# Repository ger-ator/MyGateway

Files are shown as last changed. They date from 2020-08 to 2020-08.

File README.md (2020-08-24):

# MyGateway
RFM69 + ATSHA204A Shield for Arduino.

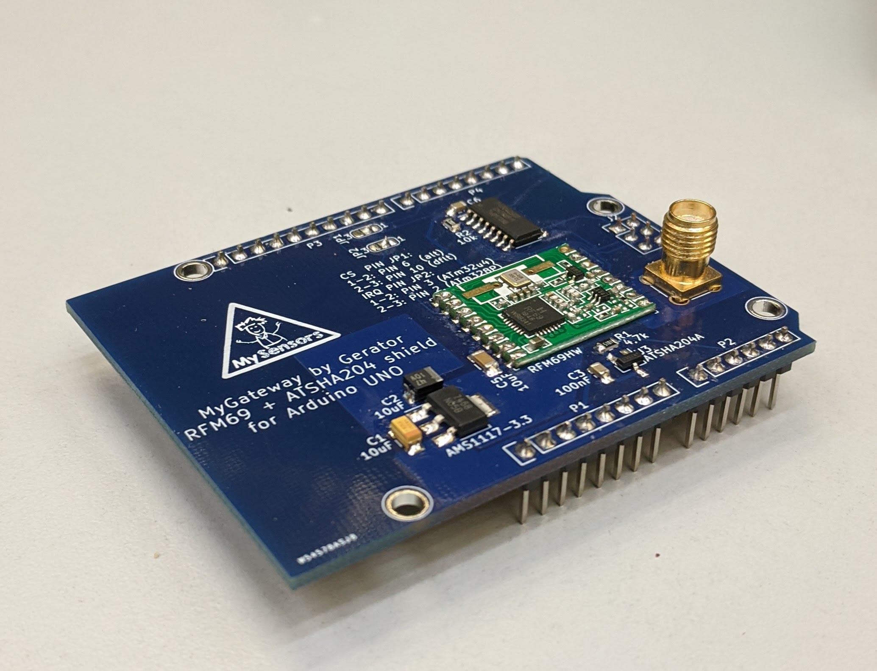
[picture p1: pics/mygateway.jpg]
MyGateway shield


# Description
This is another shield to build a MySensors gateway with Arduino UNO form factor. 
It includes RFM69 radio module and ATSHA204A crypto signing chip.

# Configuration
There are two jumpers to configure CS and IRQ RFM69 pins.
JP1 is used to choose between pins 6 or 10 for the RFM69 CS line. This is necessary to use an ethernet module in the same SPI bus.
JP2 is used to choose between pins 2 or 3 for the RFM69 IRQ line. Default for ATmega328P seems to be pin 2 but for ATmega32u4 is pin 3.
 - Serial gateway using an Arduino UNO JP1 and JP2 should be both 2-3.
 - Ethernet gateway using Arduino UNO with Ethernet shield stacked JP1 should be 1-2 and JP2 2-3.
 - Ethernet gateway with DFRobot DFR0342 JP1 and JP2 should be both 1-2.

# Compact POE powered MySensors ethernet gateway
I have been using the shield with DFRobot DFR0342 board with success. This is a very compact POE powered ethernet gateway setup. DFRobot DFR0342 board is basically an Arduino Leonardo board with built in W5500 ethernet module and POE powered.

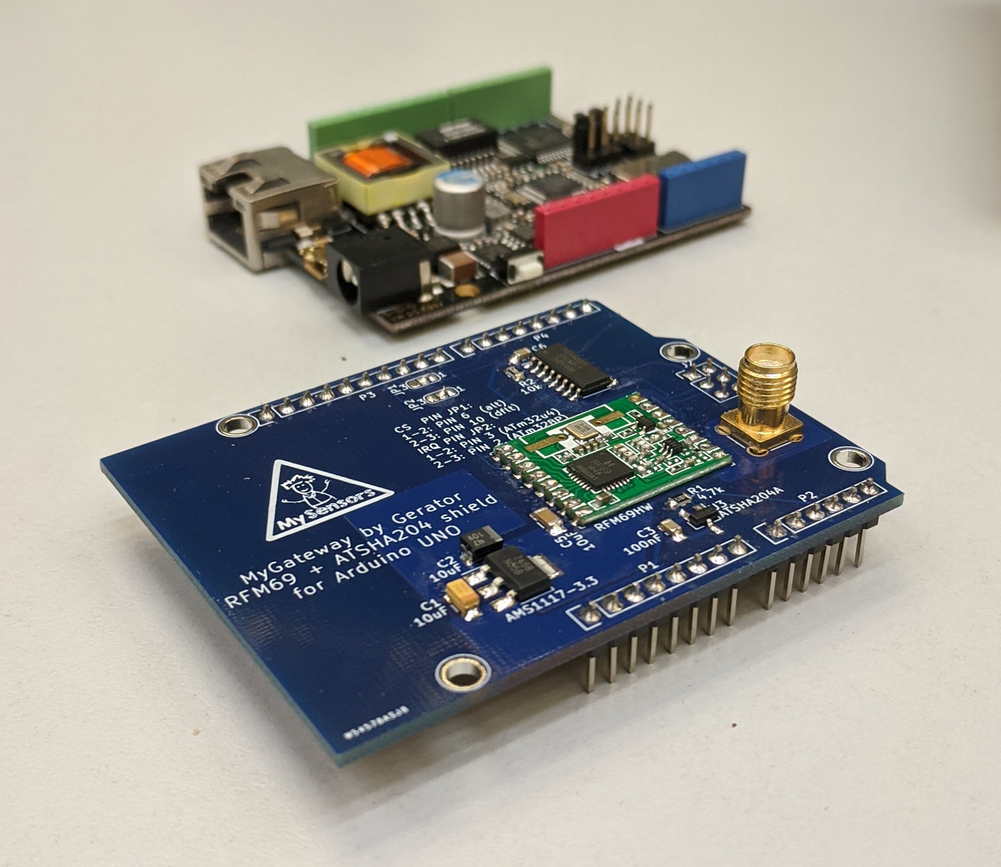
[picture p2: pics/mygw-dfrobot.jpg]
MyGateway + DFRobot board


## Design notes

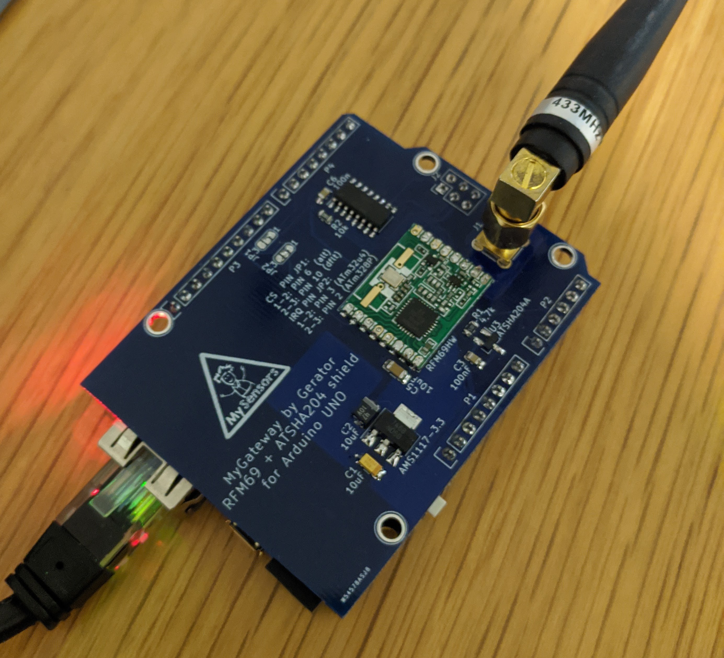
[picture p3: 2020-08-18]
pics/dfrobot_gateway.jpg

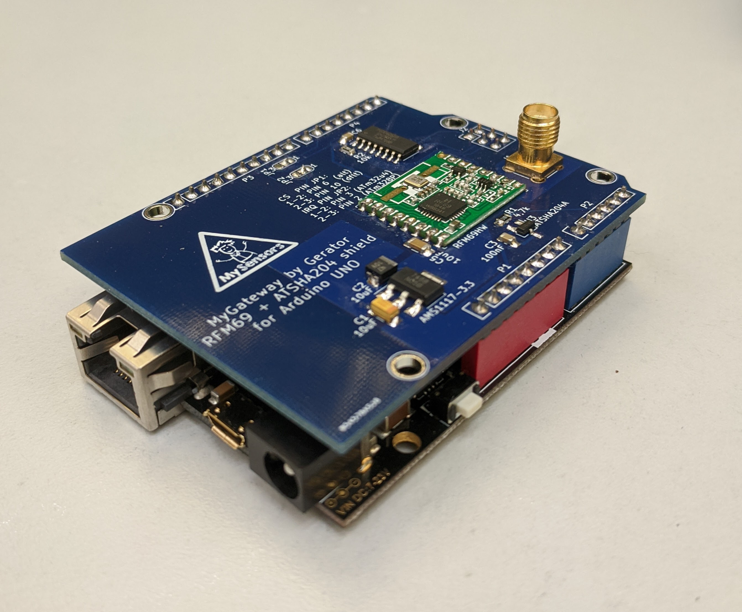
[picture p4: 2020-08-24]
pics/dfrobot_gateway2.jpg

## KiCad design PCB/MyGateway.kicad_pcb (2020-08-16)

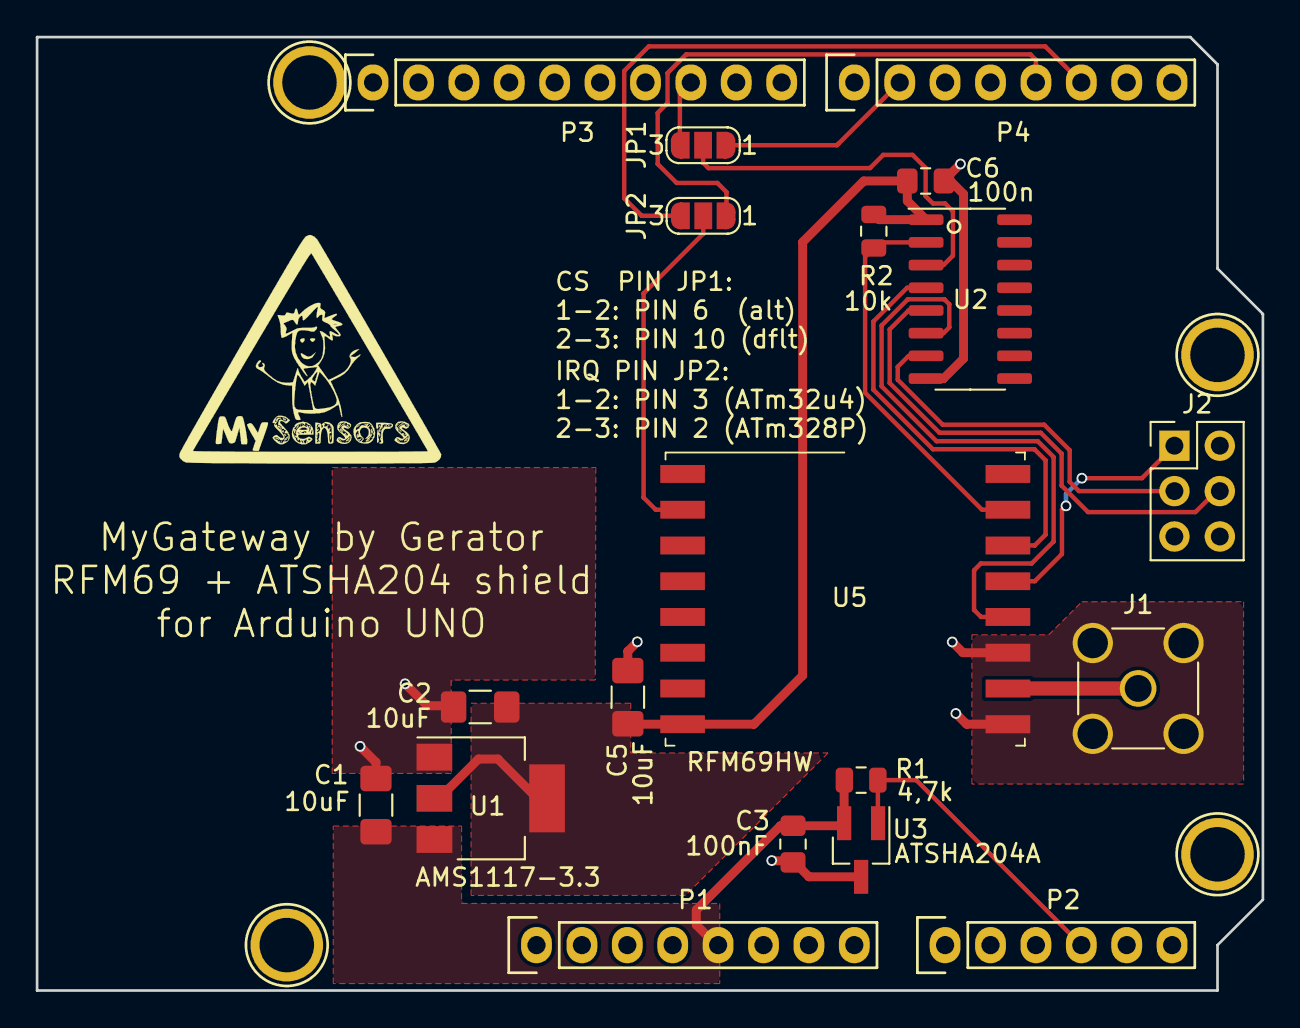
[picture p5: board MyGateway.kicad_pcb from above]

Board: 2 copper layers, 68.6 x 53.3 mm, 23 parts (0 on the bottom side), 19 nets.

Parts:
C1, C2, C5: 10uF; C_1206_3216Metric_Pad1.42x1.75mm_HandSolder
C3: 100nF; C_0805_2012Metric_Pad1.15x1.40mm_HandSolder
C6: 100n; C_0805_2012Metric_Pad1.15x1.40mm_HandSolder
J1: Conn_Coaxial; SMA_Amphenol_901-144_Vertical
J2: Conn_02x03_Odd_Even; PinHeader_2x03_P2.54mm_Vertical
JP1, JP2: SolderJumper_3_Open; SolderJumper-3_P1.3mm_Open_RoundedPad1.0x1.5mm_NumberLabels
P1: Power; Socket_Strip_Arduino_1x08
P2: Analog; Socket_Strip_Arduino_1x06
P3: Digital; Socket_Strip_Arduino_1x10
P4: Digital; Socket_Strip_Arduino_1x08
P5, P6, P7, P8: CONN_01X01; Arduino_1pin
R1: 4,7k; R_0805_2012Metric
R2: 10k; R_0805_2012Metric
U1: AMS1117-3.3; SOT-223-3_TabPin2
U2: 4050; SOIC-16_3.9x9.9mm_P1.27mm
U3: ATSHA204A; SOT-23_Handsoldering
U5: RFM69HW; HOPERF_RFM69HW

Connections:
+5V: C1.1, C3.1, P1.5, R1.1, U1.3, U3.2
/2: JP2.3, P4.6
/3(**): JP2.1, P4.5
/6(**): JP1.1, P4.2
/10(**/SS): JP1.3, P3.8
/A3: P2.4, R1.2, U3.1
/A4(SDA): P2.5, P3.2
/A5(SCL): P2.6, P3.1
/CSN: R2.2, U2.2, U5.15
/IRQ: JP2.2, U5.2
/MISO: J2.1, U5.13
/MOSI: U2.4, U5.14
/MOSI-ICSP: J2.4, U2.5
/SCK: U2.6, U5.12
/SCK-ICSP: J2.3, U2.7
GND: C1.2, C2.2, C3.2, C5.2, C6.2, J1.2, P1.6, P1.7, P3.4, U1.1, U2.8, U3.3, U5.9, U5.11
unnamed: J1.1, U5.10
unnamed: JP1.2, U2.3
VCC: C2.1, C5.1, C6.1, R2.1, U1.2, U2.1, U5.8

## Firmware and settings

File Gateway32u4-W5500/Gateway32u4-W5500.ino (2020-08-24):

/*
 * The MySensors Arduino library handles the wireless radio link and protocol
 * between your home built sensors/actuators and HA controller of choice.
 * The sensors forms a self healing radio network with optional repeaters. Each
 * repeater and gateway builds a routing tables in EEPROM which keeps track of the
 * network topology allowing messages to be routed to nodes.
 *
 * Created by Henrik Ekblad <henrik.ekblad@mysensors.org>
 * Copyright (C) 2013-2020 Sensnology AB
 * Full contributor list: https://github.com/mysensors/MySensors/graphs/contributors
 *
 * Documentation: http://www.mysensors.org
 * Support Forum: http://forum.mysensors.org
 *
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
 *******************************
 *
 * REVISION HISTORY
 * Version 1.0 - Henrik Ekblad
 * Contribution by a-lurker and Anticimex
 * Contribution by Norbert Truchsess <norbert.truchsess@t-online.de>
 * Contribution by Tomas Hozza <thozza@gmail.com>
 *
 *
 * DESCRIPTION
 * The EthernetGateway sends data received from sensors to the ethernet link.
 * The gateway also accepts input on ethernet interface, which is then sent out to the radio network.
 *
 * The GW code is designed for Arduino 328p / 16MHz.  ATmega168 does not have enough memory to run this program.
 *
 * LED purposes:
 * - To use the feature, uncomment MY_DEFAULT_xxx_LED_PIN in the sketch below
 * - RX (green) - blink fast on radio message received. In inclusion mode will blink fast only on presentation received
 * - TX (yellow) - blink fast on radio message transmitted. In inclusion mode will blink slowly
 * - ERR (red) - fast blink on error during transmission error or receive crc error
 *
 * See http://www.mysensors.org/build/ethernet_gateway for wiring instructions.
 *
 */
 
// Enable debug prints to serial monitor
//#define MY_DEBUG
#define MY_BAUD_RATE 115200

/* Disable to save flash */
#define MY_DISABLED_SERIAL
#define MY_SPLASH_SCREEN_DISABLED
#undef USBCON

// Enable and select radio type attached
#define MY_RADIO_RFM69
#define MY_IS_RFM69HW
#define MY_RFM69_NEW_DRIVER
#define MY_RFM69_FREQUENCY RFM69_433MHZ
#define MY_RFM69_IRQ_PIN 3
#define MY_RFM69_CS_PIN 6

// Enable gateway ethernet module type

/* Using fixed instead of DHCP to save flash */
#define MY_IP_ADDRESS XX,XX,XX,XX
#define MY_IP_GATEWAY_ADDRESS XX,XX,XX,XX
#define MY_IP_SUBNET_ADDRESS XX,XX,XX,XX
#define MY_GATEWAY_W5100
#define MY_PORT 5003
#define MY_MAC_ADDRESS 0xXX, 0xXX, 0xXX, 0xXX, 0xXX, 0xXX

// Enable inclusion mode

/* Disable to save flash */
#define MY_INCLUSION_MODE_FEATURE
#define MY_INCLUSION_MODE_DURATION 60 //sg
// Set blinking period
//#define MY_DEFAULT_LED_BLINK_PERIOD 300

#define MY_SIGNING_ATSHA204_PIN A3
#define MY_SIGNING_ATSHA204
#define MY_SIGNING_REQUEST_SIGNATURES

#include <Ethernet.h>
#include <MySensors.h>

void setup()
{
	// Setup locally attached sensors
}

void presentation()
{
	// Present locally attached sensors here
}

void loop()
{
	// Send locally attached sensors data here
}

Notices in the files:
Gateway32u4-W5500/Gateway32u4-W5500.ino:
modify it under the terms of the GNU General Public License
